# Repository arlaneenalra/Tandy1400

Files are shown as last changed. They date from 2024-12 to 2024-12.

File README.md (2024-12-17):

# Tandy1400 PSU

A very rough potential replacement for a Tandy 1400 PSU. At this point the board has not been tested 
in any way, shape, or form and is only published for potential review.

> [!CAUTION]
> **Do not use the 12V 1.2A power brick that comes with the Tandy 1400FD (Catalog Number 25-3501).**
> This power brick is a simple unregulated supply that may output much higher voltages than the rated 12v. The unit I examined would output 15.86v unloaded. The maximum input voltages for the MEZD41502A-C 15v DC-DC converter is 13v and I have no idea what would happen if it saw 15.86v instead.
>
> The power adapter from the 1400HD model (12v 2.2A Catalog Number 25-3505) appears to be better regulated and is what I've been using for testing.

## Status

2024-12-15 - Bug Fixes
* Upped C2 to 100uF, 47 seems to not quite be enough for the LCD to work well, you get some fading and potentially contrast issues.
* Ordered potentially replacement for the 15v DC-DC converter, if it works, I'll add the converter module to the repo and start an SMD version of the board.

2024-12-01 - Bug fixes
* This should finally fix the MEZD41502A-C footprint.
* Validated the board in "wall power only" configuration.
* At this point, the basic design has been shown to work. I'm not going to order more boards until I have a fix for the [availability issue](https://github.com/arlaneenalra/Tandy1400/issues/3).

2024-11-24 - Bug fixes
* Reversed the switch footprint. - Should orient the stock switch correctly now.
* Reversed the 15v converter and pulled in slightly from the edge of the board. This should avoid solder joints on the back of the module being too close to the shield.
* Adjusted the one mounting whole that was too close to the edge of the board.
* Added a 330uF capacitor to prevent switch induced voltage spikes from killing a TP5100 module.
* Adjusted the through holes for battery leads.

2024-11-23 - Next iteration of the board arrived
* Switch footprint works but is backwards to the original
* 15v converter still too close to the edge, needs to come in about 2~3mm
* -22v rail seems to go between -30v and -27v, need to adjust the values a bit.
* Battery wire holes are too small.
* USB connected to the Arduino Nano can feed power into the dc in bus. It won't feed into the USB connector because of a diode in the Nano, but could power the 15v converter off of the USB port, less than ideal.
* Hmm, cooked the charger board when tried to plug in while on battery power. Not sure why.

2024-11-16 - Regenerating PCB layout for new order.
* A whole bunch of minor changes that should fix the -22v boost converter.
* New switch foot print should allow for harvesting the original switch.
* Added jumpers for operation without the Arduino.
* Screw holes are now actually grounded.

2024-11-11 - Boards arrived!
* Fixed pin size and overall footprint on U2. The holes were too small and it was too close to the edge.
* Fixed diode pin sizes, I had DO-41 and the diodes are actually D201AD.
* The whole -22v boost converter doesn't work ....
* Fixed incorrect inductor connections for negative boost converter
* Fixed R6 and R4 being reversed.

2024-11-05 - Just ordered a set of boards via JLCPCB. I'll update when they are received and tested.

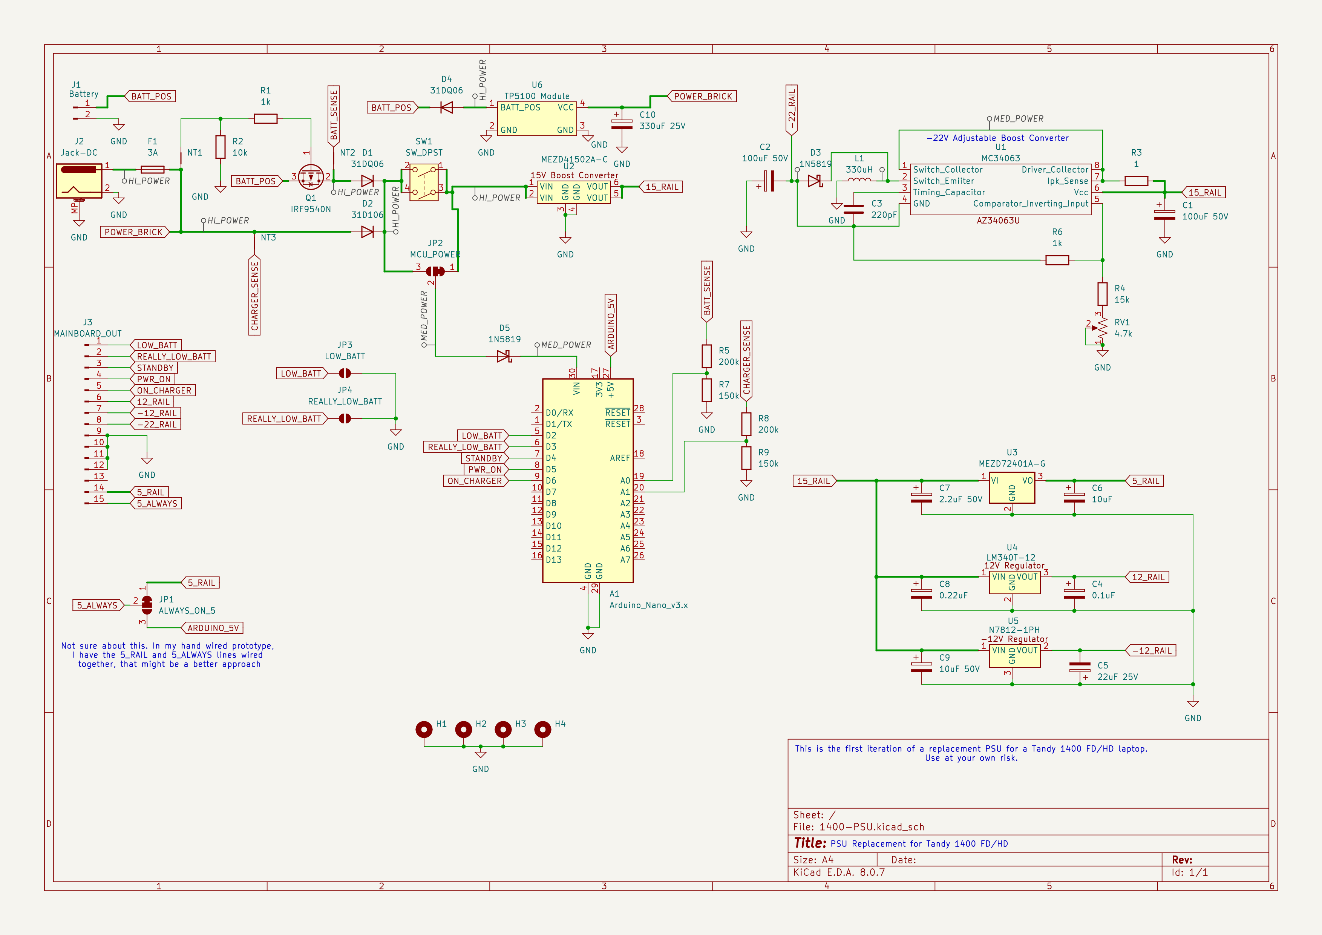
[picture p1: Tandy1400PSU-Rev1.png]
Rev 1 circuit diagram Rev1 PSU

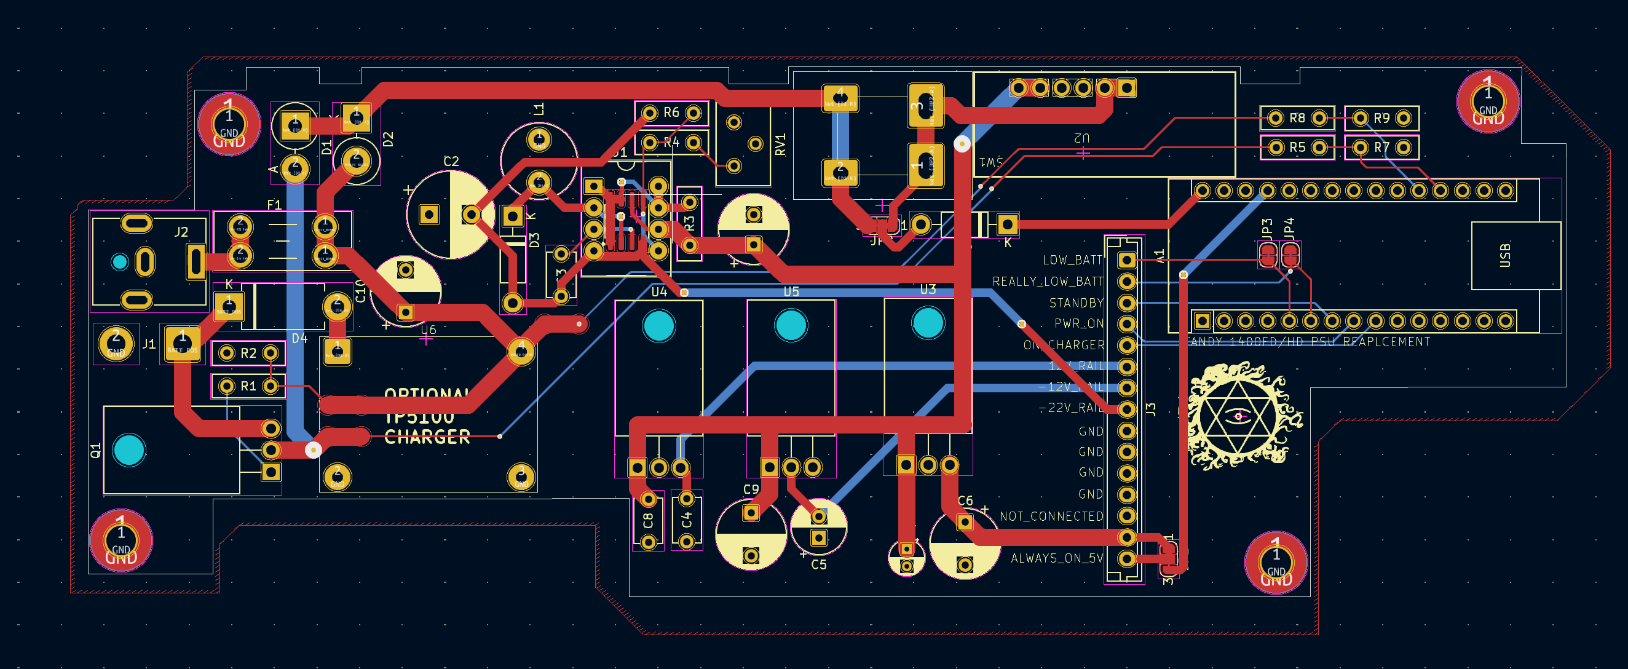
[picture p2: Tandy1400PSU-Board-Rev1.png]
Rev 1 board layout Rev1 PSU Board


# Ordering Boards

I recommend 1.6mm boards with 2oz copper. The pre-generated gerbers should be sufficient.

# Solder Jumpers

## JP1 ALWAYS_ON_5 and JP3 MCU_POWER
In the original board, there is a 5V rail that listed as always on. If you cut the 2-1 configuration of these jumpers and resolder them in 2-3 the MCU is always powered and the 5_ALWAYS
rail is powered off of the MCUs internal 5V linear regulator. I do not recommend this configuration, it is present primarily for experimentation.

## JP3 LOW_BATT and JP4 REALLY_LOW_BATT
There are two stages to the Tandy 1400s low battery behavior. The original PSU pulls these pins to ground when the battery is seen as fully charged. If you want to run without an Arduino
just short these two jumpers and it should stop the machine from continuously reporting low battery.

# Parts List

## Required
* C1, C2 - 100uF 50V
* C3 - 220pf
* C4 - 0.1uF
* C5 - 22uF 25V
* C6, C9 - 10uF 50V
* C7 - 2.2uF 50V
* C8 - 0.22uF
* D2 - 31DQ06 - 3A Power Diode
* D3 - 1N5819 - Schottky DO15 40V 1A 150C - This is like way overrated. I've been semi-successful with a 1N4148.
* F1 - Keystone 3568 (Mini Automotive Fuse Holder) - https://www.digikey.com/en/products/detail/keystone-electronics/3568/2137306
* F1 - 3 Amp Mini Automotive fuse - 2 Amp may be acceptable
* J2 - CP-063AH-ND Barrel Jack Connector - https://www.digikey.com/en/products/detail/same-sky-formerly-cui-devices/pj-063ah/2161208  
* J3 - EHR-15 and 14 ASEHSEH22K152 Jumpers - If you have an existing supply, this can be harvested off the old one.
  * https://www.digikey.com/en/products/detail/jst-sales-america-inc/EHR-15/527237
  * https://www.digikey.com/en/products/detail/jst-sales-america-inc/ASEHSEH22K152/6009479
* L1 - 330uH Inductor
* R6 - 1k 1/4w
* R3 - 1 ohm 1/4w 
* R4 - 15k 1/4w
* RV1 - 4.7k Trimmer 3296Y-1-472 or equivalent - https://www.digikey.com/en/products/detail/bourns-inc/3296Y-1-472/2536015 you want one with the adjustment on top or facing to the outer edge of the board when installed.
* SW1 - Z4418-ND - https://www.digikey.com/en/products/detail/omron-electronics-inc-emc-div/A8L-21-12N2/1811713
  * I've adjusted the footprint so that it's theoretically possible to harvest the original if you have one.
  * You might be able to harvest the switch off you're old supply, but the foot print is slightly different.
* U1 - MC34063 in either PDIP-8 or SOIC-8 form.
* U2 - MEZD41502A-C - 15V DC/DC boost converter (Digikey says it's obsolete, manufacturer didn't last I checked.) - https://www.digikey.com/en/products/detail/monolithic-power-systems-inc/MEZD41502A-C/6823857
* U3 - MEZD72401A-G - Drop in replacement for a TO-220-3 LM7805 - https://www.digikey.com/en/products/detail/monolithic-power-systems-inc/MEZD72401A-G/6823842
  * This is a 7805 equivalent rated for 1A. You could theoretically put a 7805 here, but you'd need to keep in mind heat dissipation and efficiency.
  * An alternative https://www.digikey.com/en/products/detail/monolithic-power-systems-inc/MEZD71201A-G/6823821 Should also work, really, this just needs to handle the 15v input voltage, match the 7805 pin out, and support up to 1A load.
* U4 - LM340T-12 - Note: This is powered off of a 15V rail so you'll probably need an actual linear regulator.
  * DO NOT try to use an N7812-1PH in place of the LM340T-12, this part needs a minimum of 20V to produce a +12V supply and has been seen to dump 36V out when under-voltaged.
* U5 - N7812-1PH - +/- 12V DC/DC Converter Used to generate -12V, cannot be used for +12V with a 15V supply. - https://www.digikey.com/en/products/detail/mean-well-usa-inc/N7812-1PH/22119016 
  * Keep a close eye on the pin-out for this one, the inductor goes down to match the board wiring. If installed incorrectly, the regulator is effectively dead.

## Suggested
* 3x TO-220 mounting kit - Something like https://www.digikey.com/en/products/detail/boyd-laconia-llc/4880SG/1625671
  * You may also want a bit of thermal compound (non-conductive).
  * None of the TO-220 parts should produce much heat so this may not strictly be necessary.
  * The N7812-1PH does not have a mounting hole.
  * The MEZD72401A-G uses 2.54mm header pins which are extremely difficult to bend. The board is laid out to allow it to be mounted to the board, but you may also need a small TO-220 heatsink similar to https://www.digikey.com/en/products/detail/cts-thermal-management-products/PB1-36CB/272680

* Multi-colored heatshrink tubing small diameter - If you are not harvesting the power lead off of an existing PSU board, this will help you distinguish which lead is witch in the JST connector.

## Optional
* A1 - 5v Arduino Nano (ATmega 328p based was used in prototype)
  * 2.54mm pin heade for the Arduino (28 pins)
  * R7, R9 - 150k 1/4w
  * R5, R8 - 200k 1/4w

* Battery Power
  * J1 - Jumper lead for battery connection. Size to match pack but should be able to handle at least 2A. (Through holes are sized for 18guage)
  * D1 - 31DQ06 - 3A Power Diode
  * D5 - 1N5819 - Schottky DO15 40V 1A 150C - This is like way overrated. I've been semi-successful with a 1N4148.
  * Q1 - IRF9540N P-Channel MOSFET in TO-220-3 - http://www.irf.com/product-info/datasheets/data/irf9540n.pdf
  * R1 - 1k 1/4w
  * R2 - 10k 1/4w
  * 2s Li-ion pack in the 3000mah range  - *Must have protection circuits* I would recommend 18650 based packs over Li-poly.
    * The current design uses a voltage divider at the Arduino. This could create a phantom load on the battery and drain it overtime.

* Charging - Experimental - *use at your own risk*
  * **WARNING: Cheap TP5100 charging modules have a high unexpected failure rate. If you do set this up, do not leave unattended while the machine is plugged in.**
  * D4 - 31DQ06 - Diode - D4 may just be a jumper, my TP5100 modules didn't like being connected to the battery unpowered.
  * U6 - TP5100 Charging module - https://www.amazon.com/Charging-Management-Voltage-Regulator-Batteries/dp/B0C781VGYY
    * It is recommended to remove one of the R100 resistors to drop to 1A charging.
  * C10 - 330uF 25v - The cheap TP5100 modules I've been using tend to blow up on voltage spikes without this.

* Note: Resistor wattage ratings are currently and estimate.

# References
* https://forum.vcfed.org/index.php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
* https://forum.vcfed.org/index.php?threads/dc-dc-converter-modules.1250102/
* https://www.lo-tech.co.uk/wiki/Tandy_1400FD
* [PSU Pinouts](https://docs.google.com/spreadsheets/d/1nll-RFp76xCkyXyzz_ilaRExv62mEH7IuoLMoUgfZ3Y/edit?usp=sharing)

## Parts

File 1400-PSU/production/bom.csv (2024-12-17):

Designator | Footprint | Quantity | Value | LCSC Part #
A1 | Arduino_Nano | 1 | Arduino_Nano_v3.x
C1 | CP_Radial_D8.0mm_P3.50mm | 1 | 100uF 50V
C10 | CP_Radial_D8.0mm_P5.00mm | 1 | 330uF 25V
C2 | CP_Radial_D10.0mm_P5.00mm | 1 | 100uF 50V
C3 | C_Disc_D5.1mm_W3.2mm_P5.00mm | 1 | 220pF
C4 | C_Disc_D5.1mm_W3.2mm_P5.00mm | 1 | 0.1uF
C5 | CP_Radial_D6.3mm_P2.50mm | 1 | 22uF 25V
C6 | CP_Radial_D8.0mm_P5.00mm | 1 | 10uF
C7 | CP_Radial_D4.0mm_P2.00mm | 1 | 2.2uF 50V
C8 | C_Disc_D5.1mm_W3.2mm_P5.00mm | 1 | 0.22uF
C9 | CP_Radial_D8.0mm_P5.00mm | 1 | 10uF 50V
D1 | D_DO-201AD_P5.08mm_Vertical_AnodeUp | 1 | 31DQ06
D2 | D_DO-201AD_P5.08mm_Vertical_KathodeUp | 1 | 31D106
D3, D5 | D_DO-41_SOD81_P10.16mm_Horizontal | 2 | 1N5819
D4 | D_DO-201AD_P12.70mm_Horizontal | 1 | 31DQ06
F1 | Fuseholder_Blade_Mini_Keystone_3568 | 1 | 3A
J1 | SolderWire-1.5sqmm_1x02_P7.8mm_D1.7mm_OD3.9mm | 1 | Battery
J2 | BarrelJack_CUI_PJ-063AH_Horizontal | 1 | Jack-DC
J3 | JST_EH_B15B-EH-A_1x15_P2.50mm_Vertical | 1 | MAINBOARD_OUT
L1 | L_Radial_D8.7mm_P5.00mm_Fastron_07HCP | 1 | 330uH
Q1 | TO-220-3_Horizontal_TabDown | 1 | IRF9540N
R1, R6 | R_Box_L8.4mm_W2.5mm_P5.08mm | 2 | 1k
R2 | R_Box_L8.4mm_W2.5mm_P5.08mm | 1 | 10k
R3 | R_Box_L8.4mm_W2.5mm_P5.08mm | 1 | 1
R4 | R_Box_L8.4mm_W2.5mm_P5.08mm | 1 | 15k
R5, R8 | R_Box_L8.4mm_W2.5mm_P5.08mm | 2 | 200k
R7, R9 | R_Box_L8.4mm_W2.5mm_P5.08mm | 2 | 150k
RV1 | Potentiometer_Bourns_3299Y_Vertical | 1 | 4.7k
SW1 | A8L-21-12N2 | 1 | SW_DPST
U1 | SO_PDIP-8_3.9x4.9mm_P1.27mm_1 | 1 | MC34063
U2 | Monolithic Power SIP6 | 1 | MEZD41502A-C
U3 | TO-220-3_Horizontal_TabDown | 1 | MEZD72401A-G
U4 | TO-220-3_Horizontal_TabDown | 1 | LM340T-12
U5 | TO-220-3_Horizontal_TabDown | 1 | N7812-1PH
U6 | TP5100-Module | 1 | TP5100 Module

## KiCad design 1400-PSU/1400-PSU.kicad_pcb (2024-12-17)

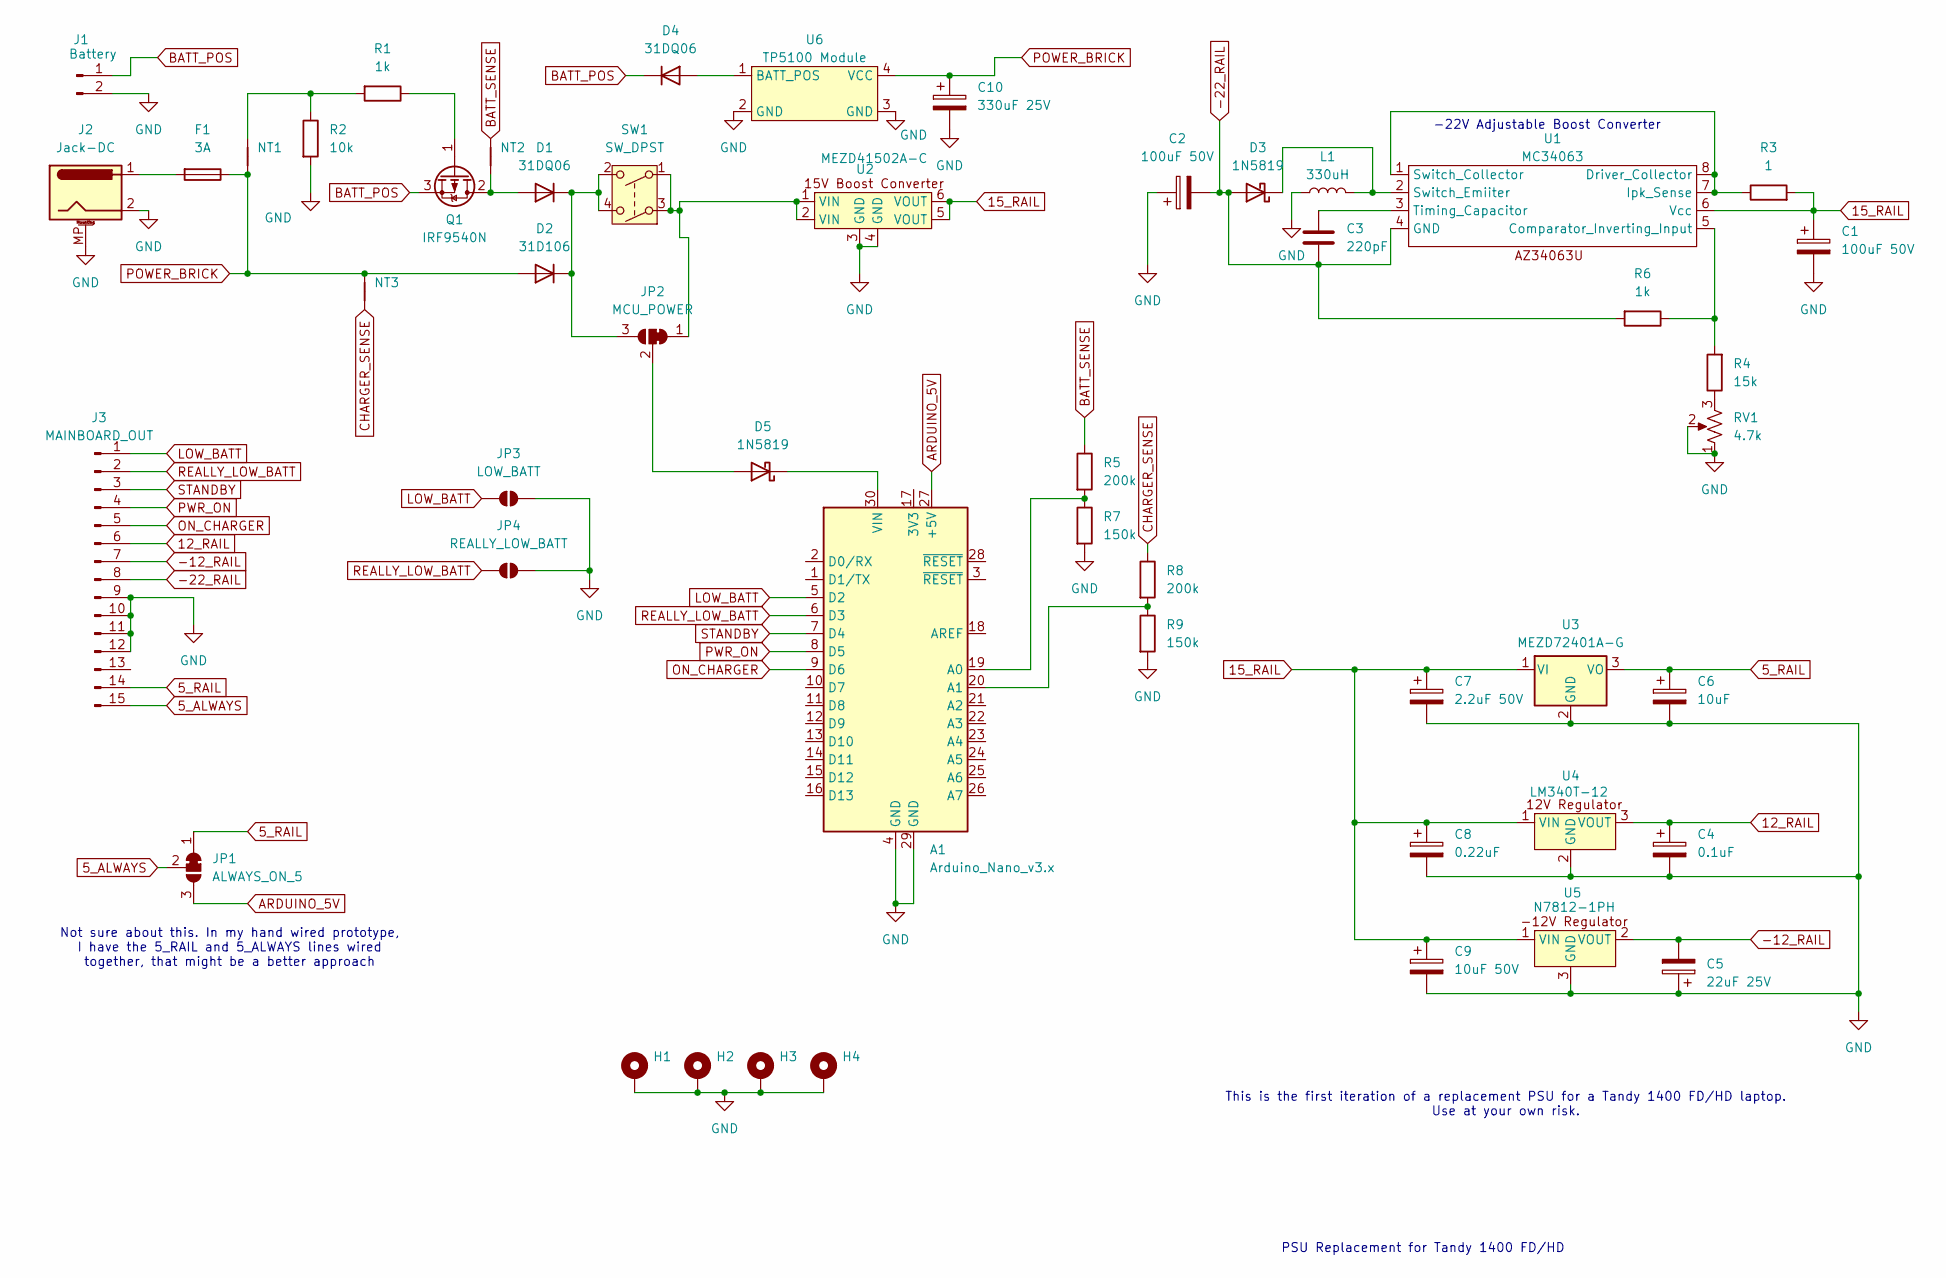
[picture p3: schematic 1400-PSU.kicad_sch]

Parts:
A1: Arduino_Nano_v3.x; Arduino_Nano
C1: 100uF 50V; CP_Radial_D8.0mm_P3.50mm
C2: 100uF 50V; CP_Radial_D10.0mm_P5.00mm
C3: 220pF; C_Disc_D5.1mm_W3.2mm_P5.00mm
C4: 0.1uF; C_Disc_D5.1mm_W3.2mm_P5.00mm
C5: 22uF 25V; CP_Radial_D6.3mm_P2.50mm
C6: 10uF; CP_Radial_D8.0mm_P5.00mm
C7: 2.2uF 50V; CP_Radial_D4.0mm_P2.00mm
C8: 0.22uF; C_Disc_D5.1mm_W3.2mm_P5.00mm
C9: 10uF 50V; CP_Radial_D8.0mm_P5.00mm
C10: 330uF 25V; CP_Radial_D8.0mm_P5.00mm
D1: 31DQ06; D_DO-201AD_P5.08mm_Vertical_AnodeUp
D2: 31D106; D_DO-201AD_P5.08mm_Vertical_KathodeUp
D3, D5: 1N5819; D_DO-41_SOD81_P10.16mm_Horizontal
D4: 31DQ06; D_DO-201AD_P12.70mm_Horizontal
F1: 3A; Fuseholder_Blade_Mini_Keystone_3568
H1, H2, H3, H4: MountingHole_3.5mm_Pad_TopBottom
J1: Battery; SolderWire-1.5sqmm_1x02_P7.8mm_D1.7mm_OD3.9mm
J2: Jack-DC; BarrelJack_CUI_PJ-063AH_Horizontal
J3: MAINBOARD_OUT; JST_EH_B15B-EH-A_1x15_P2.50mm_Vertical
JP1: ALWAYS_ON_5; SolderJumper-3_P1.3mm_Bridged12_RoundedPad1.0x1.5mm_NumberL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
JP2: MCU_POWER; SolderJumper-3_P1.3mm_Bridged12_RoundedPad1.0x1.5mm_NumberL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
JP3: LOW_BATT; SolderJumper-2_P1.3mm_Open_RoundedPad1.0x1.5mm
JP4: REALLY_LOW_BATT; SolderJumper-2_P1.3mm_Open_RoundedPad1.0x1.5mm
L1: 330uH; L_Radial_D8.7mm_P5.00mm_Fastron_07HCP
NT1, NT2, NT3: NetTie_2; NetTie-2_SMD_Pad2.0mm
Q1: IRF9540N; TO-220-3_Horizontal_TabDown
R1, R6: 1k; R_Box_L8.4mm_W2.5mm_P5.08mm
R2: 10k; R_Box_L8.4mm_W2.5mm_P5.08mm
R3: 1; R_Box_L8.4mm_W2.5mm_P5.08mm
R4: 15k; R_Box_L8.4mm_W2.5mm_P5.08mm
R5, R8: 200k; R_Box_L8.4mm_W2.5mm_P5.08mm
R7, R9: 150k; R_Box_L8.4mm_W2.5mm_P5.08mm
RV1: 4.7k; Potentiometer_Bourns_3299Y_Vertical
SW1: SW_DPST; A8L-21-12N2
U1: MC34063; SO_PDIP-8_3.9x4.9mm_P1.27mm_1
U2: MEZD41502A-C; Monolithic Power SIP6
U3: MEZD72401A-G; TO-220-3_Horizontal_TabDown
U4: LM340T-12; TO-220-3_Horizontal_TabDown
U5: N7812-1PH; TO-220-3_Horizontal_TabDown
U6: TP5100 Module; TP5100-Module

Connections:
5_ALWAYS: J3.15, JP1.2 (C)
5_RAIL: C6.1, J3.14, JP1.1 (A), U3.3 (VO)
12_RAIL: C4.1, J3.6, U4.3 (VOUT)
15_RAIL: C1.1, C7.1, C8.1, C9.1, R3.2, U1.6 (Vcc), U2.5 (VOUT), U2.6 (VOUT), U3.1 (VI), U4.1 (VIN), U5.1 (VIN)
-12_RAIL: C5.2, J3.7, U5.2 (VOUT)
-22_RAIL: C2.2, C3.2, D3.2 (A), J3.8, R6.2, U1.4 (GND)
ARDUINO_5V: A1.27 (+5V), JP1.3 (B)
BATT_POS: D4.1 (K), J1.1, Q1.3 (S)
BATT_SENSE: NT2.2, R5.1
CHARGER_SENSE: NT3.1, R8.1
GND: A1.4 (GND), A1.29 (GND), C1.2, C2.1, C4.2, C5.1, C6.2, C7.2, C8.2, C9.2, C10.2, H1.1, H2.1, H3.1, H4.1, J1.2, J2.2, J2.MP (MountPin), J3.9, J3.10, J3.11, J3.12, JP3.2 (B), JP4.2 (B), L1.1, R2.2, R7.2, R9.2, RV1.1, RV1.2, U2.3 (GND), U2.4 (GND), U3.2 (GND), U4.2 (GND), U5.3 (GND), U6.2 (GND), U6.3 (GND)
LOW_BATT: A1.5 (D2), J3.1, JP3.1 (A)
unnamed: A1.19 (A0), R5.2, R7.1
unnamed: A1.20 (A1), R8.2, R9.1
unnamed: A1.30 (VIN), D5.1 (K)
unnamed: D1.2 (A), NT2.1, Q1.2 (D)
unnamed: D1.1 (K), D2.1 (K), JP2.3 (B), SW1.2, SW1.4
unnamed: D3.1 (K), L1.2, U1.2 (Switch_Emiiter)
unnamed: D4.2 (A), U6.1 (BATT_POS)
unnamed: D5.2 (A), JP2.2 (C)
unnamed: F1.2, J2.1
unnamed: JP2.1 (A), SW1.1, SW1.3, U2.1 (VIN), U2.2 (VIN)
unnamed: NT1.2, R1.2, R2.1
unnamed: Q1.1 (G), R1.1
unnamed: R4.1, RV1.3
unnamed: R4.2, R6.1, U1.5 (Comparator_Inverting_Input)
unnamed: R3.1, U1.1 (Switch_Collector), U1.7 (Ipk_Sense), U1.8 (Driver_Collector)
unnamed: C3.1, U1.3 (Timing_Capacitor)
ON_CHARGER: A1.9 (D6), J3.5
POWER_BRICK: C10.1, D2.2 (A), F1.1, NT1.1, NT3.2, U6.4 (VCC)
PWR_ON: A1.8 (D5), J3.4
REALLY_LOW_BATT: A1.6 (D3), J3.2, JP4.1 (A)
STANDBY: A1.7 (D4), J3.3

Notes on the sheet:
This is the first iteration of a replacement PSU for a Tandy 1400 FD/HD laptop. Use at your own risk.
Not sure about this. In my hand wired prototype, I have the 5_RAIL and 5_ALWAYS lines wired together, that might be a better approach
-22V Adjustable Boost Converter
PSU Replacement for Tandy 1400 FD/HD

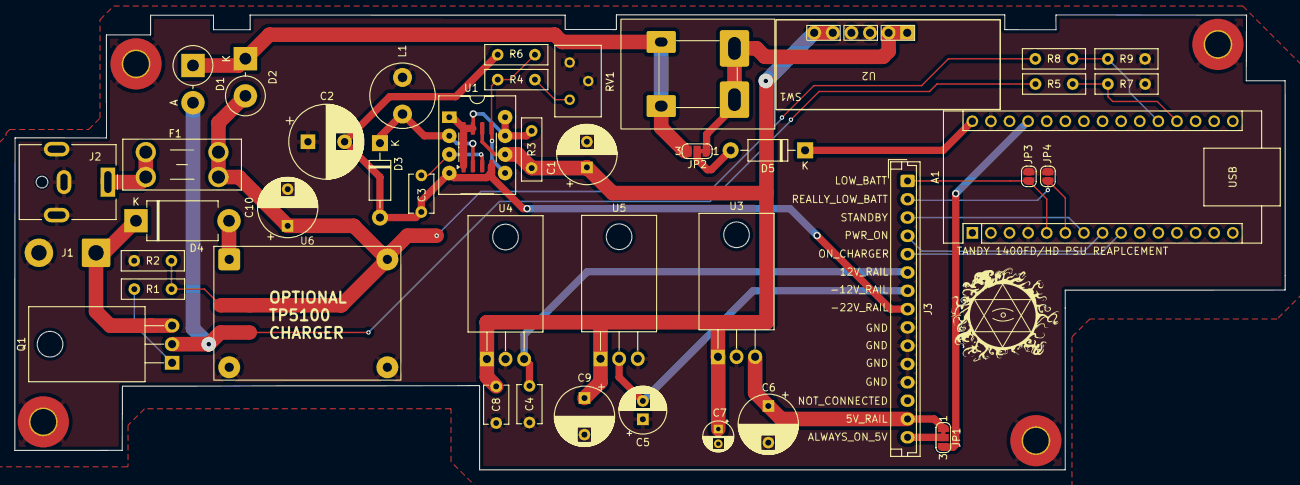
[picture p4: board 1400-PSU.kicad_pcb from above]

Board: 2 copper layers, 173.4 x 62.1 mm, 50 parts (0 on the bottom side), 33 nets.

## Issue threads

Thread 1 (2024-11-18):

LOW_BATT and REALLY_LOW_BATT shorted on board.

arlaneenalra, 2024-11-18:
This should be pretty easy to bodge around but would cause issues with low battery and really low battery warnings being on almost all the time.
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

arlaneenalra, 2024-11-18:
doh, the other line is on the bottom layer, this looks like a problem but itsn't.

Closed 2024-11-18.

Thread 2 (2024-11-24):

TP5100 module fails when connecting and disconnecting under load.

arlaneenalra, 2024-11-24:
I've seen the TP5100 module release the magic smoke (literally though with very little visible damage) on a few occasions when connecting power to the PSU board, especially when it's under load (i.e. the system is booted).

The TP5100 modules I've seen are common and all seem to have the same configuration. (See https://www.jotrin.com/technology/details/tp5100-lithium-battery-charger-module for the common configuration).

By default, the come configured for 2A charging (with to 0.1ohm resistors in parallel to get 0.05ohm). This configuration seems to be the absolute maximum of the board. It's possible there's a transient on connection that pulls damages the chip or that something is over currenting the chip.

See: http://toppwr.com/uploadfile/file/20230304/6402f53e7e8d9.pdf

A couple of theories:
* The 2A charge rate runs too close to the boards maximum and a transient during charger insertion overloads it.
* There could be an input voltage dip when the charger is plugged in due to the load on the 15v converter and the start up current of the charging unit. The 1400HD power brick is rated for 12V@2.2A, it's possible the input voltage to the switching unit in the TP5100 drops when connected under load and over currents the module.

Possible fix:
* Pull one of the 0.1ohm resistors to drop the charging current down to 1A instead of the 2A it ships with.

arlaneenalra, 2024-11-24:
Charging current alone is not the answer. I had a module setup for 1A toast itself when I turned flipped the power switch while the unit was plugged in charging.

arlaneenalra, 2024-11-24:
Further evidence that this module is basically junk https://secondlifestorage.com/index.php?threads/we-have-ignition-tp5100-fiery-fail.10753/ ... from what I can tell, it's missing filtering capacitors and seems to be known to just straight up fail when running anywhere close to 12v input .. hmm.

arlaneenalra, 2024-11-24:
Looks like the addition of a 330uF capacitor might actually solve the issue. https://www.reddit.com/r/PCB/comments/1gy4iw2/comment/lyowm1n/  When switching you get a voltage spike the external supply that can jump to +20v. Well above the absolute maximums of the TP5100 chip. Based on the document linked in that comment, this can be made worse by ceramic capacitors on the charging module. Attaching a 330uF electrolytic to the input seems to be enough to prevent the chip from going boom. At least in the units I've got. I'm also reducing the charging current by removing one of the 0.1ohm resistors just to be on the safe side. The whole external supply can only handle 2.2a and this module is supposed to be able to draw 2a on it's own, reducing the charging current should pull it back into a safe range for the external brick. (at least on the HD variant).

Closed 2024-11-26.

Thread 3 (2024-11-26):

Sourcing MEZD41502A-C could be difficult

arlaneenalra, 2024-11-26:
Digikey claims the part is obsolete and no longer manufactured https://www.digikey.com/en/products/detail/monolithic-power-systems-inc/MEZD41502A-C/6823857 ...
The manufacturer says otherwise https://www.monolithicpower.com/en/mezd41502a-c.html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 (at least right now..) they call the part active.

Mouser is also listing it as out of stock with almost a year of factory lead time https://www.mouser.com/ProductDetail/Monolithic-Power-Systems-MPS/mEZD41502A-C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 ...

Though I'm seeing that a number of suppliers are having issues getting the part. Might need to find an alternative.

arlaneenalra, 2024-11-26:
hmm.. I'm seeing it available via https://www.dyethin.com/productdetails/monolithic-power-systems-inc-mezd41502a-c and https://www.allicdata.com/products/mezd41502a-c/45799.html but I'm not overly familiar with those companies. It would not surprise me to find this is going to start becoming hard to find in the US.

arlaneenalra, 2024-12-12:
Waiting on parts to show up at my supplier to send a possible replacement design for testing..

arlaneenalra, 2024-12-21:
Candidate boards arrived and work pretty much identically to the original part. Which is not unexpected since they are based on the reference circuit from the original part with a redone layout. Unfortunately, they are about $20 a pop vs $12ish for the original. As a replacement for when supplies of the existing 15v part run out, that's probably fine. It also validates the idea of building an SMD version of the board for PCB assembly. Though that could involve resourcing/redesigning some of the power rails. I think I'm going to close this out and hold onto the 15v converter design since the original is still available right now.

Closed 2024-12-21.

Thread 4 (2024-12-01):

15v DC-DC converter placment too close to power swtich

arlaneenalra, 2024-12-01:
The reverse positioning solves the issue with the converter being too close to the outside shielding, but leaves it in conflict with the power switch.
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

Closed 2024-12-02.

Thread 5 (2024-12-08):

Low battery detection not working right.

arlaneenalra, 2024-12-08:
I ran the battery down far enough that the my 1400 wouldn't power on correctly after being powered off. I didn't leave it on for very long and it recovered fine once plugged into the wall for a while. The problem is that I'm not getting low battery warnings. I suspect that the voltage level detection isn't working right. I'm not sure if it's the voltage divider of the arduino code.

arlaneenalra, 2024-12-08:
Yeah, I was playing around with the voltage dividers and I have those setup way wrong. Not sure how I got them that far off. R8 and R5 should be about 200K not 10k

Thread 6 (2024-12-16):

Having USB attached to Arduino in circuit powers 15V converter

arlaneenalra, 2024-12-16:
I discovered that having a usb cable connected to the Arduino when it's in circuit powers the 15V converter from the USB cable. If the arduino is never programmed in circuit (i.e. socketed) this isn't a big deal. It could pose a problem if there the board is programed while connected to a machine though.

The fix would be to add a diode to the input line for the Arduino to avoid back feeding the rest of the PSU. (Maybe another 1N5819?) All of the input voltages should be high enough for that not to cause problems.

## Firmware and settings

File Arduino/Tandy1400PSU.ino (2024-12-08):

// For this board setup with a 200k/150k voltage divder I'm getting a consistent 0.0107v  per unit.
// This puts 12v right at the the very top of our range though my Arduino seems to handle that ok.


// For a 2s battery anything the maximum charge voltage is roughly 8.4v which gives us 722 as fully charged.
// The Tandy 1400 seems to cut out around 6.7~6.6 and not want to start up again, at least with the pack I'm
// using. That puts "Dead Dead" at around 6.7v.
// For mostly discharged we're somewhere around 575 which gives us a range of about 150 give or take.

#define ON_CHARGER 900

#define DEAD_BATTERY 575
#define REALLY_LOW_BATTERY 600
#define LOW_BATTERY 620
#define FULL_BATTERY 722

const int sensePin = A0;
const int chargerSensePin = A1;

// white - out
const int lowBatteryOne = 2;
// dark blue - out
const int lowBatteryTwo = 3;
// gray - out
const int powerSwitchOn = 5;
// brown - in
const int standBy = 4;
// light blue - out
const int onMains = 6;


void setup() {
  ///analogReference(DEFAULT);

  // Setup pins
  pinMode(lowBatteryOne, OUTPUT);
  pinMode(lowBatteryTwo, OUTPUT);
  pinMode(powerSwitchOn, INPUT);
  pinMode(onMains, OUTPUT);

  pinMode(standBy, INPUT);

  // This is always on, the original supply had it wired directly to the power switch.
  //digitalWrite(powerSwitchOn, HIGH);

  // Serial Console
  Serial.begin(115200);
}

void loop() {
  int newLowBatteryOne = HIGH;
  int newLowBatteryTwo = HIGH;
  int newOnMains = LOW;

  int newStandBy = digitalRead(standBy);
  int powerOn = digitalRead(powerSwitchOn);
  int sense = analogRead(sensePin);
  int chargerSense = analogRead(chargerSensePin);

  // Check if we're on mains.
  if (chargerSense > ON_CHARGER) {
    newOnMains = HIGH;

    // if we're on wall power, we don't need a low battery warning.
    newLowBatteryOne = LOW;
    newLowBatteryTwo = LOW;
  }

  // Check if we have a low battery.
  if (sense > LOW_BATTERY) {
    newLowBatteryOne = LOW;
  }

  // Check for a really low battery.
  if (sense > REALLY_LOW_BATTERY) {
    newLowBatteryTwo = LOW;
  }

  // Write Updated values.
  digitalWrite(lowBatteryOne, newLowBatteryOne);
  digitalWrite(lowBatteryTwo, newLowBatteryTwo);
  digitalWrite(onMains, newOnMains);

  if (Serial) {
    // Log Values.
    Serial.print("In Batt voltage : ");
    Serial.print(sense);
    Serial.print(" In Charge voltage : ");
    Serial.print(chargerSense);
    Serial.print(" low1: ");
    Serial.print(newLowBatteryOne);
    Serial.print(" low2: ");
    Serial.print(newLowBatteryTwo);
    Serial.print(" mains: ");
    Serial.print(newOnMains);
    Serial.print(" standBy: ");
    Serial.print(newStandBy);
    Serial.print(" powerOn: ");
    Serial.print(powerOn);
    Serial.print(" ref: ");
    Serial.print(DEFAULT);
    Serial.print(" ");
    Serial.print(INTERNAL);
    Serial.print(" ");
    Serial.print(EXTERNAL);
    Serial.print(" ");
    Serial.print("\n");
  }
  delay(400);
}

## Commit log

2024-11-04 Inital import.
    [1400-PSU.kicad_pcb, 1400-PSU.kicad_sch]
2024-11-05 Generated gerbers.
    [1400-PSU-B_Cu.gbl, 1400-PSU-B_Mask.gbs, 1400-PSU-B_Paste.gbp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]
2024-11-16 Updating for next board revision.
    [1400-PSU-B_Cu.gbl, 1400-PSU-B_Mask.gbs, 1400-PSU-B_Paste.gbp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]
2024-11-16 Update to readme and BOM.
    [1400-PSU-B_Cu.gbl, 1400-PSU-B_Mask.gbs, 1400-PSU-B_Paste.gbp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]
2024-11-16 Generating new gerbers.
2024-11-16 Minor README updates.
    [1400-PSU.kicad_sch]
2024-11-23 Minor updates, still need to figure out the charging issue and move the 15v converter down.
    [1400-PSU.kicad_sch]
2024-11-23 Nuke the old gerbers for now. I'll re-make them after the next update.
    [1400-PSU-B_Cu.gbl, 1400-PSU-B_Mask.gbs, 1400-PSU-B_Paste.gbp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]
2024-11-23 Move one of the mounting holes a bit.
    [1400-PSU.kicad_pcb]
2024-11-24 Minor revisions.
    [1400-PSU.kicad_pcb, 1400-PSU.kicad_sch]
2024-11-24 Generate new gerbers.
    [1400-PSU-B_Cu.gbl, 1400-PSU-B_Mask.gbs, 1400-PSU-B_Paste.gbp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]
2024-12-01 Update README.md
    Add warning about the 1400FD power brick .. wow that scared me.
2024-12-02 Should fix #4.
    [1400-PSU-B_Cu.gbl, 1400-PSU-B_Mask.gbs, 1400-PSU-B_Paste.gbp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]
2024-12-05 Note about alternatives for the 5v regulator.
2024-12-05 KiCad updates.
2024-12-08 Adjust battery warning voltage dividers.
    [1400-PSU.kicad_pcb, 1400-PSU.kicad_sch]
2024-12-08 Update to Arduino code.
2024-12-15 Minor update and fixes.
    [1400-PSU.kicad_pcb, 1400-PSU.kicad_sch]
2024-12-17 resolve #6
    [1400-PSU-B_Cu.gbl, 1400-PSU-B_Mask.gbs, 1400-PSU-B_Paste.gbp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]
